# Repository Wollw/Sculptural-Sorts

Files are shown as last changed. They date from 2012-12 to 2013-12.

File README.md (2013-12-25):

#Sculptural Sorts#

This is my independent study project for the Spring of 2013.  See 'proposal.pdf'
for more details.  The code here is for an ATtiny13 with three TPIC6B595 shift
registers to visually display the operation of a sorting algorithm.

##Resources##
*   [Sorting Out Sorting](http://youtu.be/SJwEwA5gOkM)
*   [Sorting Algorithm Animations](http://www.sorting-algorithms.com/)

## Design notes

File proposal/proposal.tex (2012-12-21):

\documentclass[12pt,a4paper]{article}
\usepackage{graphicx}

\newcommand{\doctitle}{%
Sculptural Illustration of Algorithms}

\pagestyle{myheadings}
\markboth{\hfill\doctitle}{\doctitle\hfill}

\bibliographystyle{siam}

%\addtolength{\textwidth}{1.00in}
%\addtolength{\textheight}{1.00in}
%\addtolength{\evensidemargin}{-1.00in}
%\addtolength{\oddsidemargin}{-0.00in}
%\addtolength{\topmargin}{-.50in}

\hyphenation{in-de-pen-dent}

\title{\textbf{\doctitle}\\
Independent Study Project Proposal}

\author{David E. Shere}

\begin{document}

\thispagestyle{empty}

\maketitle

My intention with this project is to build at least one sculpture in a series
with the purpose of artistically illustrating the operation of various sorting
algorithms\cite{wiki:sorting_algorithm}.  The sculptures will be constructed out
of either wood or a plastic and will use lighting acrylic on top of high power
LEDs to illustrate the sorting algorithms, which will be implemented on
microcontrollers powering the LEDs.  The two main objectives of this project
will be to explore the areas where technology and art meet, and secondarily to
improve my skills at using tools such as table and chop saws to construct
objects.  Michael McGinnis would be my supporting instructor and provide
feedback and input about my progress and ideas.  I will meet with him on
Wednesdays from 1PM to 4PM weekly.  On occasion, I might meet instead from 9AM to
12PM or on Mondays if there is a reason that would work better.

\subsection*{Exploring the Boundaries of Technology and Art}

The primary objective of this project will be to spend time investigating the
use of technology in creating sculptural works of art.  This project will
require the use of both computer engineering and artistic skills.  The computer
engineering side will involve the understanding of the algorithms that will be
illustrated and the ability to build the software that will power the
illustration.  The artistic side will be exercised by the aesthetic decisions in
terms of the display of the algorithm, and by the skill required to build a well
constructed sculpture.

Most of the technological parts of this project will be done at home where I
have the parts and equipment necessary to build the required circuit.  Ideally I
would use tricolor RGB (Red Green Blue) LEDs in order to use a wide variety of
colors but if I cannot afford to buy them I will use two colored LEDs instead
and simply create a gradient between the two colors.  A
microcontroller will have a collection of different colors
randomize, and step by step sort them into order.  In the case of the colors red,
yellow, green, and blue, it may start with the ordering "Blue, Red, Green,
Yellow," and then step by step rearrange the colors until they are in the proper
spectral order of "Red, Yellow, Green, Blue."  If I use two color LEDs it will
instead sort itself into a gradation between the two colors, such as a
continuation from blue to red with shades of violet forming the middle values.

The sculptural aspect of this work will be in determining the best way to
present this sorting.  My current idea is to create a long, segmented box
divided into spaces that will each contain a single LED (see figure
\ref{fig:diagram}).  Above each box will be a smaller rectangular box containing
a single white LED that will indicate which position the computer is currently
sorting.  The result will be a kinetic sculpture that gradually moves from a
random initial state to an ordered final state.

\subsection*{Gaining Experience with Construction Equipment}

Though the main objective for this project it to learn more about incorporating
technology and art together another motivation is to gain more experience using
the tools available in the sculpture workshop.  While taking Intermediate and
Advanced Sculpture I used the table and chop saws a great deal when working on
my projects.  While I have a fairly solid understanding of how to use these
tools I feel I could stand to get more comfortable with them.  Working on this
project would give me the opportunity to learn more about their effective use
including the use of specialized jigs and fixtures.

\subsection*{Evaluation of Work}

The way I plan to work on this project is by doing most of the technological
work at home and doing the actual building of the visible sculpture on campus.
The first half of the semester would probably be mostly spent developing the
software and electronics that would power the sculpture while evaluating
possible arrangements of the lights with maquettes.  At mid-semester I should
have a fairly complete design for the software, electronics, and the sculpture's
actual form.  The second half of the semester would be spend building the actual
piece or pieces.  Throughout the semester I would be meeting with Michael
McGinnis for his input and expertise.  The project will be graded in a verbal
critique of the work with Michael McGinnis at midterm and finals week and he
will also assign a written grade.

\bibliography{proposal}

\pagebreak
\begin{figure}[here]
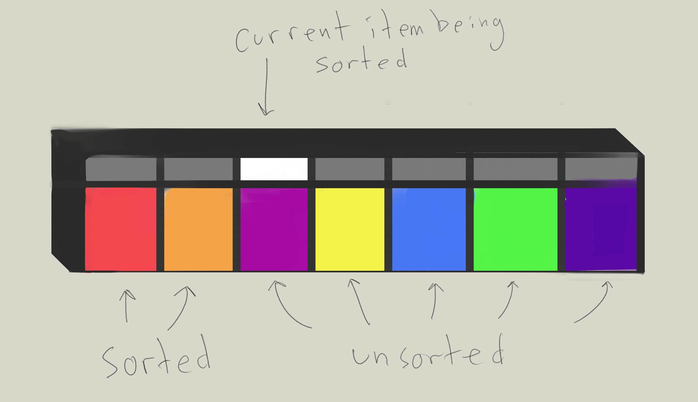
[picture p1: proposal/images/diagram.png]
    
    \caption{Diagram of a possible manifestation of one sculpture in the series.}
    \label{fig:diagram}
\end{figure}

\end{document}

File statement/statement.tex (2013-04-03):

\documentclass[12pt,letter]{article}
\usepackage{graphicx}
\usepackage{graphics}
\usepackage{listings}
\usepackage{caption}
\usepackage{color}
\usepackage{xcolor}
\usepackage{titling}

% Code Display Settings
\lstset{
    basicstyle=\footnotesize\ttfamily,
    numberstyle=\tiny,
    numbersep=5pt,
    tabsize=2,
    extendedchars=true,
    breaklines=true,
    keywordstyle=\color{red},
        frame=b,
    stringstyle=\color{white}\ttfamily,
    showspaces=false,
    showtabs=false,
    xleftmargin=17pt,
    framexleftmargin=17pt,
    framexrightmargin=5pt,
    framexbottommargin=4pt,
    showstringspaces=false
}
\lstloadlanguages{C}

\DeclareCaptionFont{white}{\color{white}}
\DeclareCaptionFormat{listing}{
    \colorbox[cmyk]{0.43, 0.35, 0.35, 0.01}{
        \parbox{\textwidth}{\hspace{15pt}#1#2#3}
    }
}
\captionsetup[lstlisting]{
    format=listing,
    labelfont=white,
    textfont=white,
    singlelinecheck=false,
    margin=0pt,
    font={bf,footnotesize}
}

\newcommand{\subtitle}[1]{%
  \posttitle{%
    \par\end{center}
    \begin{center}\large#1\end{center}
    \vskip0.5em}%
}

\bibliographystyle{siam}

%\addtolength{\textwidth}{1.00in}
%\addtolength{\textheight}{1.00in}
%\addtolength{\evensidemargin}{-1.00in}
%\addtolength{\oddsidemargin}{-0.00in}
%\addtolength{\topmargin}{-.50in}

\hyphenation{in-de-pen-dent}

\begin{document}

\title{Sculptural Sorts}
\subtitle{An Artistic Investigation of Sorting Algorithms}
\author{David E. Shere}

\maketitle
%%%%%%%%%%%%%%%%%%%% Main Document %%%%%%%%%%%%%%%%%%%%
The modern society in which we live is increasingly reliant on technology
for its day to day functions.
In spite of this,
many people are still ignorant of even the basics of
how the devices they rely on work;
for many they are magical boxes handed down by the priests of technology.
In recent years this divide between those who understand technology and
the general population has grown.
The success of tablet computers and personal computers
which leave the user with little or no access to the system internals
seems to indicate that most people don't want to know more.
However, it is the openness of earlier popular platforms that gave users
the opportunity to discover the world being closed off.
Without this openness the barriers for entry into the world of technological
understanding will continue to grow.

\cite{wiki:sorting_algorithm}

%%%%%%%%%%%%%%%%%%%% Program Code  %%%%%%%%%%%%%%%%%%%%
\pagebreak
\lstinputlisting[label=main.c, caption=Main Program {[}main.c{]}]{../src/main.c}
\lstinputlisting[label=shift.h, caption=LED Shift Register Defines {[}shift.h{]}]{../src/shift.h}
\lstinputlisting[label=util.h, caption=Utility Defines {[}util.h{]}]{../src/util.h}
\lstinputlisting[label=sorts/sorts.h, caption=Sort Declarations {[}sorts/sorts.h{]}]{../src/sorts/sorts.h}
\lstinputlisting[label=sorts/bubble.c, caption=Bubble Sort {[}sorts/bubble.c{]}]{../src/sorts/bubble.c}
\lstinputlisting[label=sorts/heap.c, caption=Heap Sort {[}sorts/heap.c{]}]{../src/sorts/heap.c}
\lstinputlisting[label=sorts/selection.c, caption=Selection Sort {[}sorts/selection.c{]}]{../src/sorts/selection.c}
\lstinputlisting[label=sorts/insertion.c, caption=Insertion Sort {[}sorts/insertion.c{]}]{../src/sorts/insertion.c}
\lstinputlisting[label=sorts/shell.c, caption=Shell Sort {[}sorts/shell.c{]}]{../src/sorts/shell.c}

%%%%%%%%%%%%%%%%%%%% Bibliography  %%%%%%%%%%%%%%%%%%%%
\pagebreak
\bibliography{statement}

\end{document}

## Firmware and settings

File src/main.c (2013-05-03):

#include <stdlib.h>
#include <stdbool.h>
#include <avr/io.h>
#include <util/delay.h>

#define DELAY_MS    750
#define COLOR_COUNT 2

#define SHFT_DDR    DDRB
#define SHFT_PORT   PORTB
#define SHFT_SER_IN PIN0
#define SHFT_RCK    PIN1
#define SHFT_SRCK   PIN2
#define SHFT_G      PIN3
#define SHFT_SRCLR  PIN4

enum { LED_ON
     , LED_OFF
     };

void sort(uint8_t*, uint8_t);
void show_state(uint8_t*, uint8_t, uint8_t);
void shift_init(void);
void shift_begin(void);
void shift_end(void);
void shift_bit(bool);

uint8_t a[8];
int main(void) {
    shift_init();
    srandom(0);
    for(;;) {
        for (int i = 0; i < 8; i++)
            a[i] = ((uint8_t)random()) % COLOR_COUNT;
        sort(a, 8);
        show_state(a, 8, 255);
    }
}

void shift_init(void) {
    SHFT_DDR |= _BV(SHFT_SER_IN)
             |  _BV(SHFT_RCK)
             |  _BV(SHFT_SRCK)
             |  _BV(SHFT_G)
             |  _BV(SHFT_SRCK);
    _delay_us(100);
}

void shift_begin(void) {
    SHFT_PORT |= _BV(SHFT_G)
              |  _BV(SHFT_SRCLR);
    _delay_us(100);
}

void shift_end(void) {
    SHFT_PORT |= _BV(SHFT_RCK);
    _delay_us(100);
    SHFT_PORT &= ~_BV(SHFT_RCK);
    _delay_us(100);
    SHFT_PORT &= ~_BV(SHFT_G);
    _delay_us(100);
}

void shift_bit(bool bit) {
    if (bit)
        SHFT_PORT |= _BV(SHFT_SER_IN);
    else
        SHFT_PORT &= ~_BV(SHFT_SER_IN);
    _delay_us(100);
    SHFT_PORT |= _BV(SHFT_SRCK);
    _delay_us(100);
    SHFT_PORT &= ~_BV(SHFT_SRCK);
    _delay_us(100);
}

void show_state(uint8_t a[], uint8_t len, uint8_t pos) {
    shift_begin();
    for (int8_t i = len - 1; i >= 0; i--) {
        switch (a[i]) {
            case LED_ON:  shift_bit(true); break;
            case LED_OFF:  shift_bit(false);  break;
        }
    }
    for (int8_t i = len - 1; i >= 0; i--) {
            shift_bit(i != pos);
    }
    shift_end();
    _delay_ms(DELAY_MS/3);
    _delay_ms(DELAY_MS/3);
    _delay_ms(DELAY_MS/3);
}

/* BUBBLE SORT */
/*
void sort(uint8_t a[], uint8_t len) {
    uint8_t swapped;
    uint8_t i, tmp;
    for (;;) {
        swapped = 0;
        for (i = 0; i < len-1; i++) {
            show_state(a, len, i);
            if (a[i+1] < a[i]) {
                tmp = a[i];
                a[i] = a[i+1];
                a[i+1] = tmp;
                swapped = 1;
            }
        }
        show_state(a, len, i);
        if (!swapped)
            break;
    }
}
*/

/* INSERTION SORT */
void sort(uint8_t a[], uint8_t len) {
    uint8_t i, j, t;
    for (i = 1; i < len; i++) {
        show_state(a, len, i);
        for (j = i; j > 0 && a[j] < a[j-1]; j--) {
            t = a[j];
            a[j] = a[j-1];
            a[j-1] = t;
            show_state(a, len, j-1);
        }
    }
}

/* SELECTION SORT */
/*
void sort(uint8_t a[], uint8_t len) {
    uint8_t i, j, k, t;
    for (i = 0; i < len; i++) {
        k = i;
        show_state(a, len, i);
        for (j = i + 1; j < len; j++) {
            show_state(a, len, j);
            if (a[j] < a[k]) {
                k = j;
            }
        }
        if (k != i) {
            if (k != j-1)
                show_state(a, len, k);
            t = a[i];
            a[i] = a[k];
            a[k] = t;
        }
        if (i+1 != len)
            show_state(a, len, i);
        else
            show_state(a, len, -1);
    }
}
*/

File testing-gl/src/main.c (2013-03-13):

#include <stdio.h>
#include <stdlib.h>
#include <stdint.h>
#include <unistd.h>
#include <stdbool.h>

#include <time.h>
#include <pthread.h>
#include <semaphore.h>

#define GL_GLEXT_PROTOTYPES
#include <GL/glut.h>

#include "util.h"
#include "shader.h"

#include "../../src/sorts/sorts.h"
#include "../../src/util.h"

/***********************/
/* Shared Declarations */
/***********************/
/** Yeah, this should be implemented with a mutex... I'm being bad here
 * because I want to use the same source as the AVR code for testing
 * purposes and don't want to litter those files with preprocessor code...
 */
volatile int position;         // current sort position.
volatile bool updated = false; // flag to trigger redraw
uint8_t a[8];         // sorting array

/*******************************/
/* Sorting Thread Declarations */
/*******************************/
void *sort_thread_fn(void *);
void sort_apply_fn(uint8_t *, uint8_t, uint8_t);

/*****************************/
/* OpenGL Thread Declaration */
/*****************************/
void draw(void);
void resize(int, int);
void idle(void);

GLint program;
GLint vertexBuffer;
GLint vPosition;
GLint uColor;
GLint uOffset;

static const GLfloat vertex_data[] = { 
    -0.5, -0.5, 0.0,
    -0.5,  0.5, 0.0,
     0.5, -0.5, 0.0,
     0.5,  0.5, 0.0
};

const GLfloat colors[3][4] = {
    {0.5, 1.0, 0.5, 0.0},   // Green
    {0.0, 1.0, 1.0, 0.0},   // Cyan
    {0.5, 0.5, 1.0, 0.0}    // Blue
};


int main(int argc, char **argv) {
    /* GLUT setup */
    glutInit(&argc, argv);
    glutInitDisplayMode(GLUT_SINGLE | GLUT_RGBA);
    int wd = glutCreateWindow("Sorting Test");
    glutDisplayFunc(draw);
    glutReshapeFunc(resize);
    glutIdleFunc(idle);

    /* GLSL program setup */
    program = create_shader_program_from_file("res/shader.vert", "res/shader.frag").prog;
    vPosition = glGetAttribLocation(program, "vPosition");
    uColor = glGetUniformLocation(program, "uColor");
    uOffset = glGetUniformLocation(program, "uOffset");
    glEnableVertexAttribArray(vPosition);
    CHECK_GL();

    /* Copy vertex data to GPU */
    glGenBuffers(1, &vertexBuffer);
    glBindBuffer(GL_ARRAY_BUFFER, vertexBuffer);
    glBufferData(GL_ARRAY_BUFFER, sizeof(vertex_data), vertex_data, GL_STATIC_DRAW);
    glBindBuffer(GL_ARRAY_BUFFER, 0);
    CHECK_GL();


    /* Create sorting thread*/
    pthread_t pth;
    pthread_create(&pth, NULL, sort_thread_fn, NULL);

    /* Start OpenGL loop */
    glutMainLoop();

    pthread_join(pth, NULL);
    return 0;
}

/***********************/
/* Sorting Thread Code */
/***********************/

/* Main function for the sorting thread. */
void *sort_thread_fn(void *v) {
    srand(time(0));
    for(;;) {
        for (uint8_t i = 0; i < LENGTH(a); i++) {
            a[i] = rand() % 3;
        }
        SORT_APPLY(ALGORITHM, a, sort_apply_fn);
        updated = true;
        position = -1;
        sleep(3);
    }
}

/* Function executed for each step of the sorting algorithm.
 * Prints to stdout for testing.
 *      int a[]    -- The current state of the array being sorted.
 *      size_t len -- The length of the array.
 *      size_t pos -- The position of the sorting cursor in the array. */
void sort_apply_fn(uint8_t a[], uint8_t len, uint8_t pos) {
    while (updated);
    uint8_t i;
    for (i = 0; i < len; i++)
        printf("%5s  ", i == pos ? "v" : " ");
    puts("");
    for (i = 0; i < len; i++) {
        printf(i == len - 1? "%5d" : "%5d, ", a[i]);
    }
    puts("");
    position = pos;
    updated = true;
    sleep(1);
}

/**********************/
/* OpenGL Thread Code */
/**********************/

void draw(void) {

    glClearColor(0.0, 0.0, 0.0, 1.0);
    glClear(GL_COLOR_BUFFER_BIT);

    glUseProgram(program);
    glBindBuffer(GL_ARRAY_BUFFER, vertexBuffer);
    glEnableVertexAttribArray(vPosition);
    glVertexAttribPointer(vPosition, 3, GL_FLOAT, GL_FALSE, 0, 0);

    // Draw sorting position.
    for (uint8_t i = 0; i < sizeof(a); i++) {
        float color = i == position ? 1 : 0.25;
        glUniform4f(uColor, color, color, color , 1.0);
        glUniform2f(uOffset, i * 1.1, +0.25);
        glDrawArrays(GL_TRIANGLE_STRIP, 0, 4);
    }

    // Draw sorting array.
    for (uint8_t i = 0; i < sizeof(a); i++) {
        float r = colors[a[i]][0];
        float g = colors[a[i]][1];
        float b = colors[a[i]][2];
        glUniform4f(uColor, r, g, b, 1);
        glUniform2f(uOffset, i * 1.1, -0.25);
        glDrawArrays(GL_TRIANGLE_STRIP, 0, 4);
    }

    glBindBuffer(GL_ARRAY_BUFFER, 0);

    glFlush();

    updated = false;
}

void resize(int w, int h) {
    if (w < h)
        glViewport(0, 0, w, w);
    else
        glViewport(0, 0, h, h);

}

void idle(void) {
    if (updated)
        glutPostRedisplay();
}

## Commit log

2012-12-22 Fixed serial bug. Forgot to initialize serial.
    [main.c]
2012-12-22 I think it's working. Just need to build the full circuit to test.
2012-12-24 Moved swap function's position in main.c
    [main.c]
2012-12-25 Fixed a bug in the Selection Sort. Added the Insertion Sort.
2012-12-26 changed the starting array to 8 elements after remembering my circuit only has enough space for 8 LEDs...
2012-12-27 Added Heap Sort. The current heap sort algorithm is a recursive algorithm and should be replaced with an iterative version.
    [sort.sch]
2012-12-27 Also added schematics in the last commit.
2013-01-23 Added materials list with cut sizes for the box parts.
2013-01-23 Removed MATERIALS.md and started a parts.svg file instead.
2013-02-06 Added dxf parts file.
    [parts.dxf]
2013-02-18 fixed the aspect ratio on the gl test
    [main.c]
2013-02-20 Changed random behaviour from randomizing a preset array to creating an array of random elements. Fixed a race condition in the opengl test.
    [main.c]
2013-02-20 fixed some problems with opaque parts. added lighting parts
    [parts.dxf]
2013-03-06 Cleaned up source a bit and added comments. Fixed scoping in SHIFT_OUT macro to allow it to be a simple expression. Moved array declaration to global scope to save two bytes.
    [main.c]
2013-05-03 Finished Insertion Sort sculpture.
